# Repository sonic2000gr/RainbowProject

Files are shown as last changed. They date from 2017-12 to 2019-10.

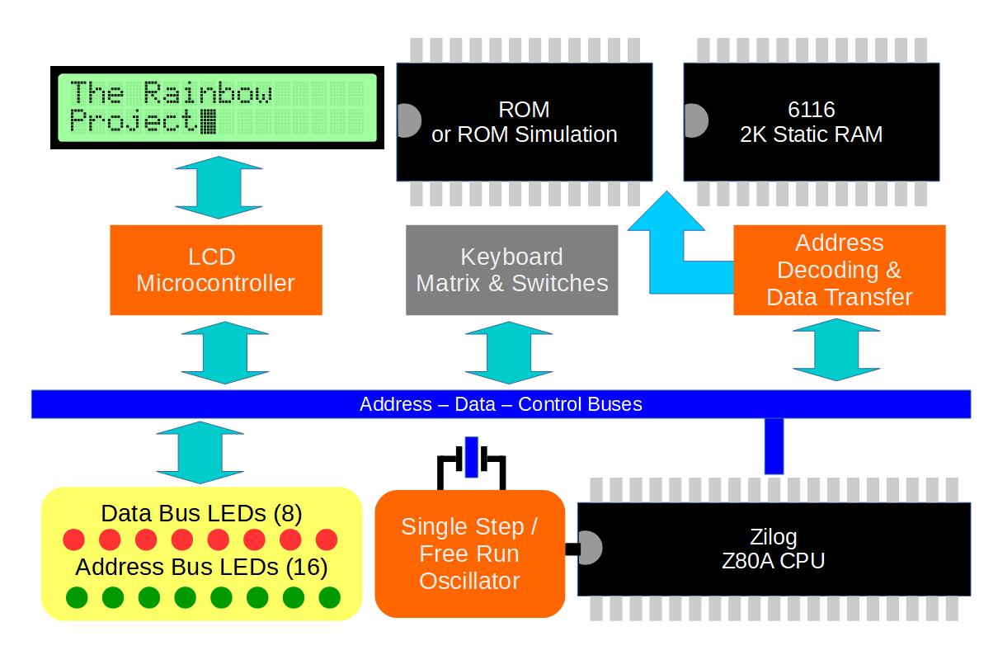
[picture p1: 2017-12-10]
graphics/rainbow diagram.jpg

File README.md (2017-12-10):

<h1>The Rainbow Z80 Project</h1>

<h2>English Version</h2>

This repository contains schematics and info on the Rainbow Project.
This is a long overdue (27 years!) project to create a  Z80 based educational computer. It is inspired by the home micros of the 80s
that used the popular 8bit processor from Zilog.

The Rainbow Project machine planned initial specs are:

<ul>
<li>Z80 CPU with variable clock (0 Hz to maybe 2-4 MHz)</li>
<li>8KB EEPROM hosting monitor / test programs</li>
<li>2KB of static RAM</li>
<li>LCD 20 characters by 4 rows or similar</li>
<li>Status LEDs for all buses (Data, Address, Control)</li>
<li>Possibly HEX keypad for entering opcodes / data</li>
<li>Other features that will come by while experimenting!</li>
</ul>

<h2>Greek Version</h2>

Το παρόν repository περιέχει σχηματικά και πληροφορίες για το Rainbow Project
Το Rainbow Project είναι ένα έργο που έχει αργήσει *μόνο* 27 χρόνια! Άρχισα να το σχεδιάζω το 1990 και πολλά από τα εξαρτήματα του (CPU, RAM)
είχαν αγοραστεί τότε. Τελικά θα πραγματοποιηθεί ως Project του <a href="http://www.schoolspace.gr">SchoolSpace</a> το σχολικό έτος 2017-2018.
Το Rainbow Project είναι εμπνευσμένο από τα πολλά μηχανήματα της δεκαετίας του 80 που βασίζονταν στο δημοφιλή επεξεργαστή Z80 της Zilog.
Χαρακτηριστικά παραδείγματα: 

<ul>
<li>Siclair ZX80 / ZX81 / Spectrum</li>
<li>Amstrad CPC</li>
<li>MSX</li>
</ul>

Οι αρχικές προδιαγραφές του μηχανήματος (θα μεταβληθούν στην πορεία):

<ul>
<li>Επεξεργαστής Z80 με μεταβλητό ρολόι (από 0 Hz ως ίσως 2 ή 4 MHz)</li>
<li>8KB EEPROM με πρόγραμμα monitor και demos / tests</li>
<li>2KB Static RAM</li>
<li>Οθόνη LCD 20X4 η παρόμοια (με οδήγηση από Arduino ή MSP430)</li>
<li>Φωτεινές ενδείξεις με LEDs για όλους τους διαύλους. Το μηχάνημα θα χρησιμοποιείται για εκπαιδευτικούς σκοπούς και θα μπορεί να δείχνει
τα βήματα ανάκλησης / εκτέλεσης εντολών</li>
<li>Πληκτρολόγιο HEX για opcodes / data</li>
<li>Ότι άλλη ιδέα μας έρθει στο μεταξύ!</li>
</ul>

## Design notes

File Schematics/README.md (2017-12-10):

This directory contains schematics in KiCad for the Z80 Rainbow Project

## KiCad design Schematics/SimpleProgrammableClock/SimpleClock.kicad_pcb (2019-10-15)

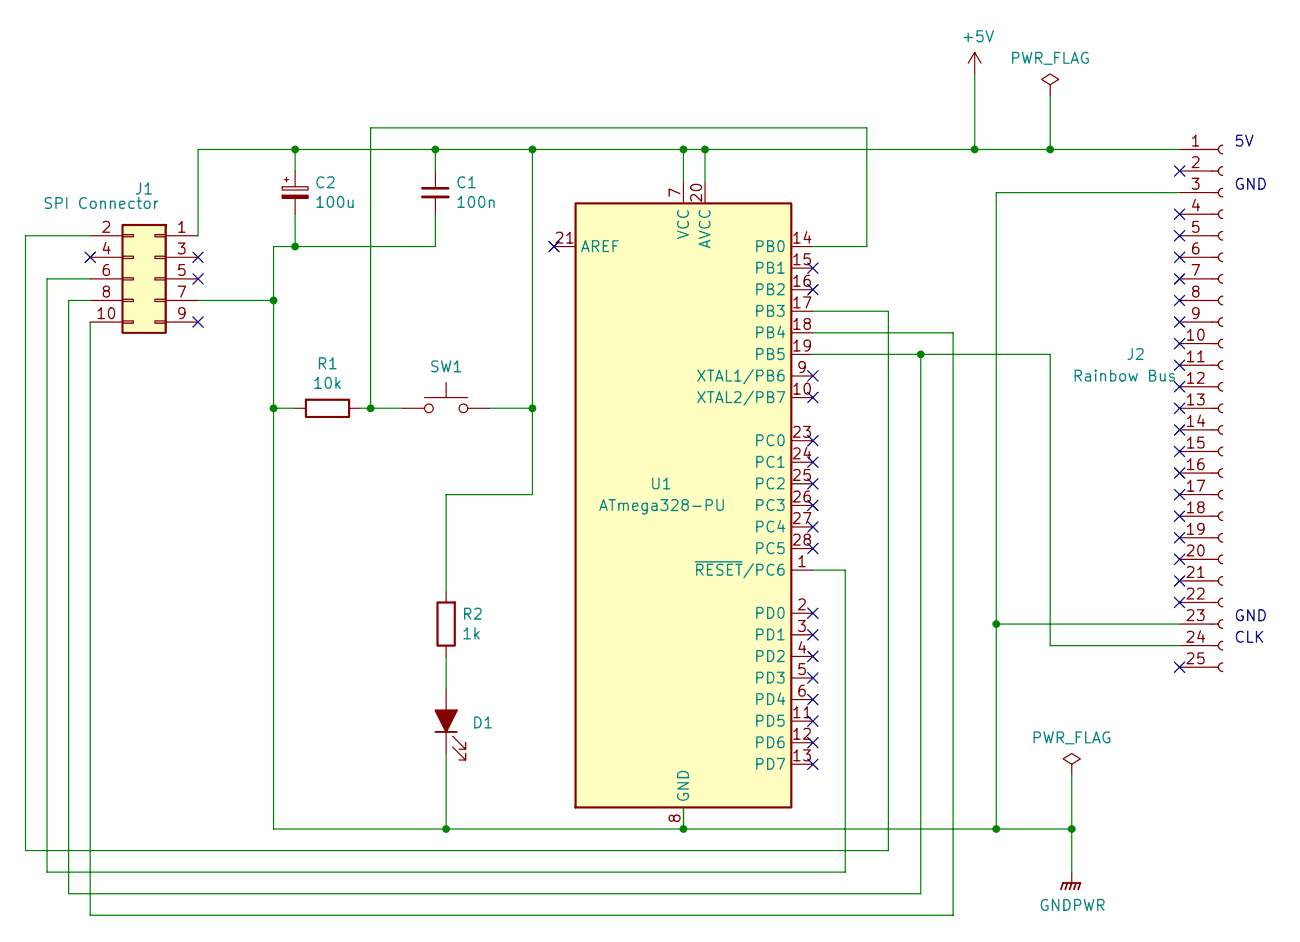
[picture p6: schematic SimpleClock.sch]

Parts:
C1: 100n; C_Disc_D5.1mm_W3.2mm_P5.00mm
C2: 100u; CP_Radial_D8.0mm_P3.50mm
D1: LED_ALT; D_DO-15_P12.70mm_Horizontal
J1: SPI Connector; PinHeader_2x05_P2.54mm_Vertical
J2: Rainbow Bus; PinHeader_1x25_P2.54mm_Vertical
R1: 10k; R_Axial_DIN0207_L6.3mm_D2.5mm_P10.16mm_Horizontal
R2: 1k; R_Axial_DIN0207_L6.3mm_D2.5mm_P10.16mm_Horizontal
SW1: SW; SW_PUSH_6mm_H4.3mm
U1: ATmega328-PU; DIP-28_W7.62mm

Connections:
+5V: C1.1, C2.1, J1.1, J2.1, R2.2, SW1.2, U1.7 (VCC), U1.20 (AVCC)
GNDPWR: C1.2, C2.2, D1.1 (K), J1.7, J2.3, J2.23, R1.2, U1.8 (GND), U1.22 (GND)
unnamed: D1.2 (A), R2.1
unnamed: J1.2, U1.17 (PB3)
unnamed: J1.6, U1.1 (~RESET~/PC6)
unnamed: J1.8, J2.24, U1.19 (PB5)
unnamed: J1.10, U1.18 (PB4)
unnamed: R1.1, SW1.1, U1.14 (PB0)

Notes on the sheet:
CLK
GND

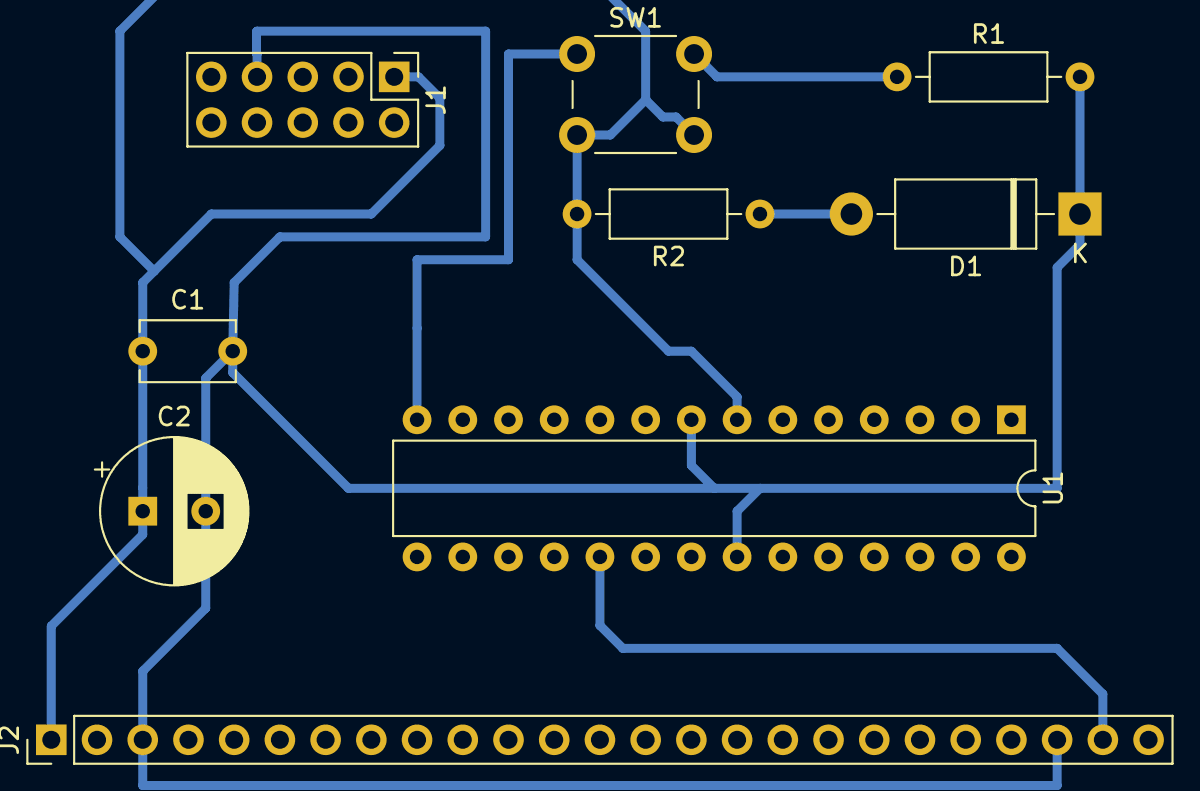
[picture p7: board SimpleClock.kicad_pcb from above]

Board: 2 copper layers, 9 parts (0 on the bottom side), 8 nets.

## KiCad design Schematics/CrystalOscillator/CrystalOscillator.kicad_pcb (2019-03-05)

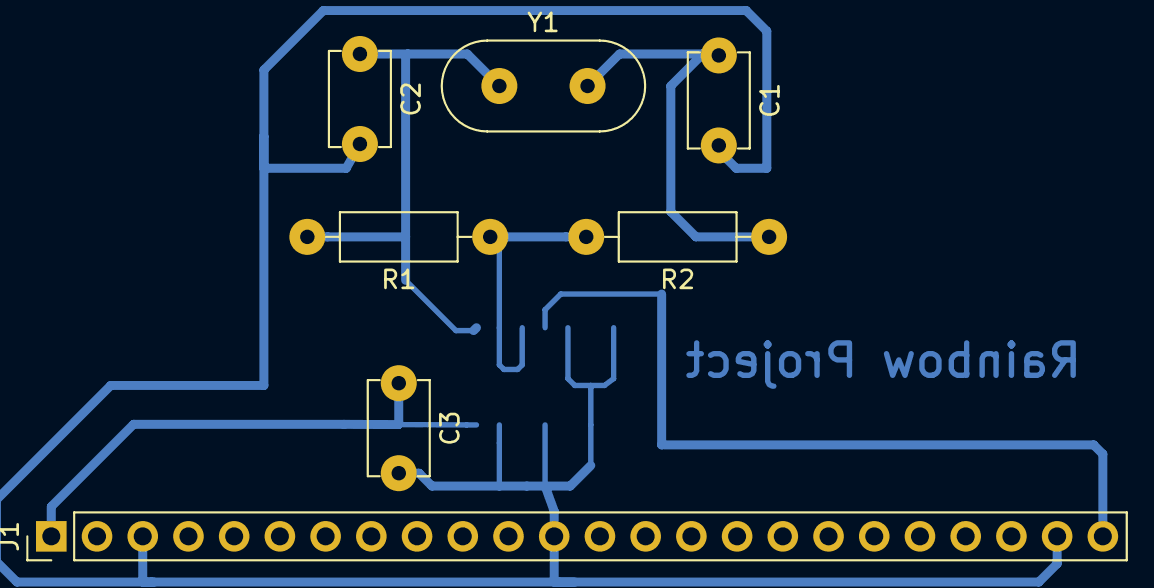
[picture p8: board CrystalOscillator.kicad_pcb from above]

Board: 2 copper layers, 8 parts (1 on the bottom side), 6 nets.

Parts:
C1, C2: 3.3p; C_Disc_D5.1mm_W3.2mm_P5.00mm
C3: 0.1u; C_Disc_D5.1mm_W3.2mm_P5.00mm
J1: Conn_01x24_Female; PinHeader_1x24_P2.54mm_Vertical
R1: 1M; R_Axial_DIN0207_L6.3mm_D2.5mm_P10.16mm_Horizontal
R2: 10k; R_Axial_DIN0207_L6.3mm_D2.5mm_P10.16mm_Horizontal
U1: 74HC14; SOIC-14_3.9x8.7mm_P1.27mm
Y1: 4MHz Crystal; Crystal_HC18-U_Vertical

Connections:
GND: C1.2, C2.2, C3.2, J1.3, J1.12, J1.23, U1.5, U1.7, U1.9, U1.11, U1.13
unnamed: C1.1, R2.1, Y1.2
unnamed: C2.1, R1.2, U1.1, Y1.1
unnamed: J1.24, U1.4
unnamed: R1.1, R2.2, U1.2, U1.3
VCC: C3.1, J1.1, U1.14

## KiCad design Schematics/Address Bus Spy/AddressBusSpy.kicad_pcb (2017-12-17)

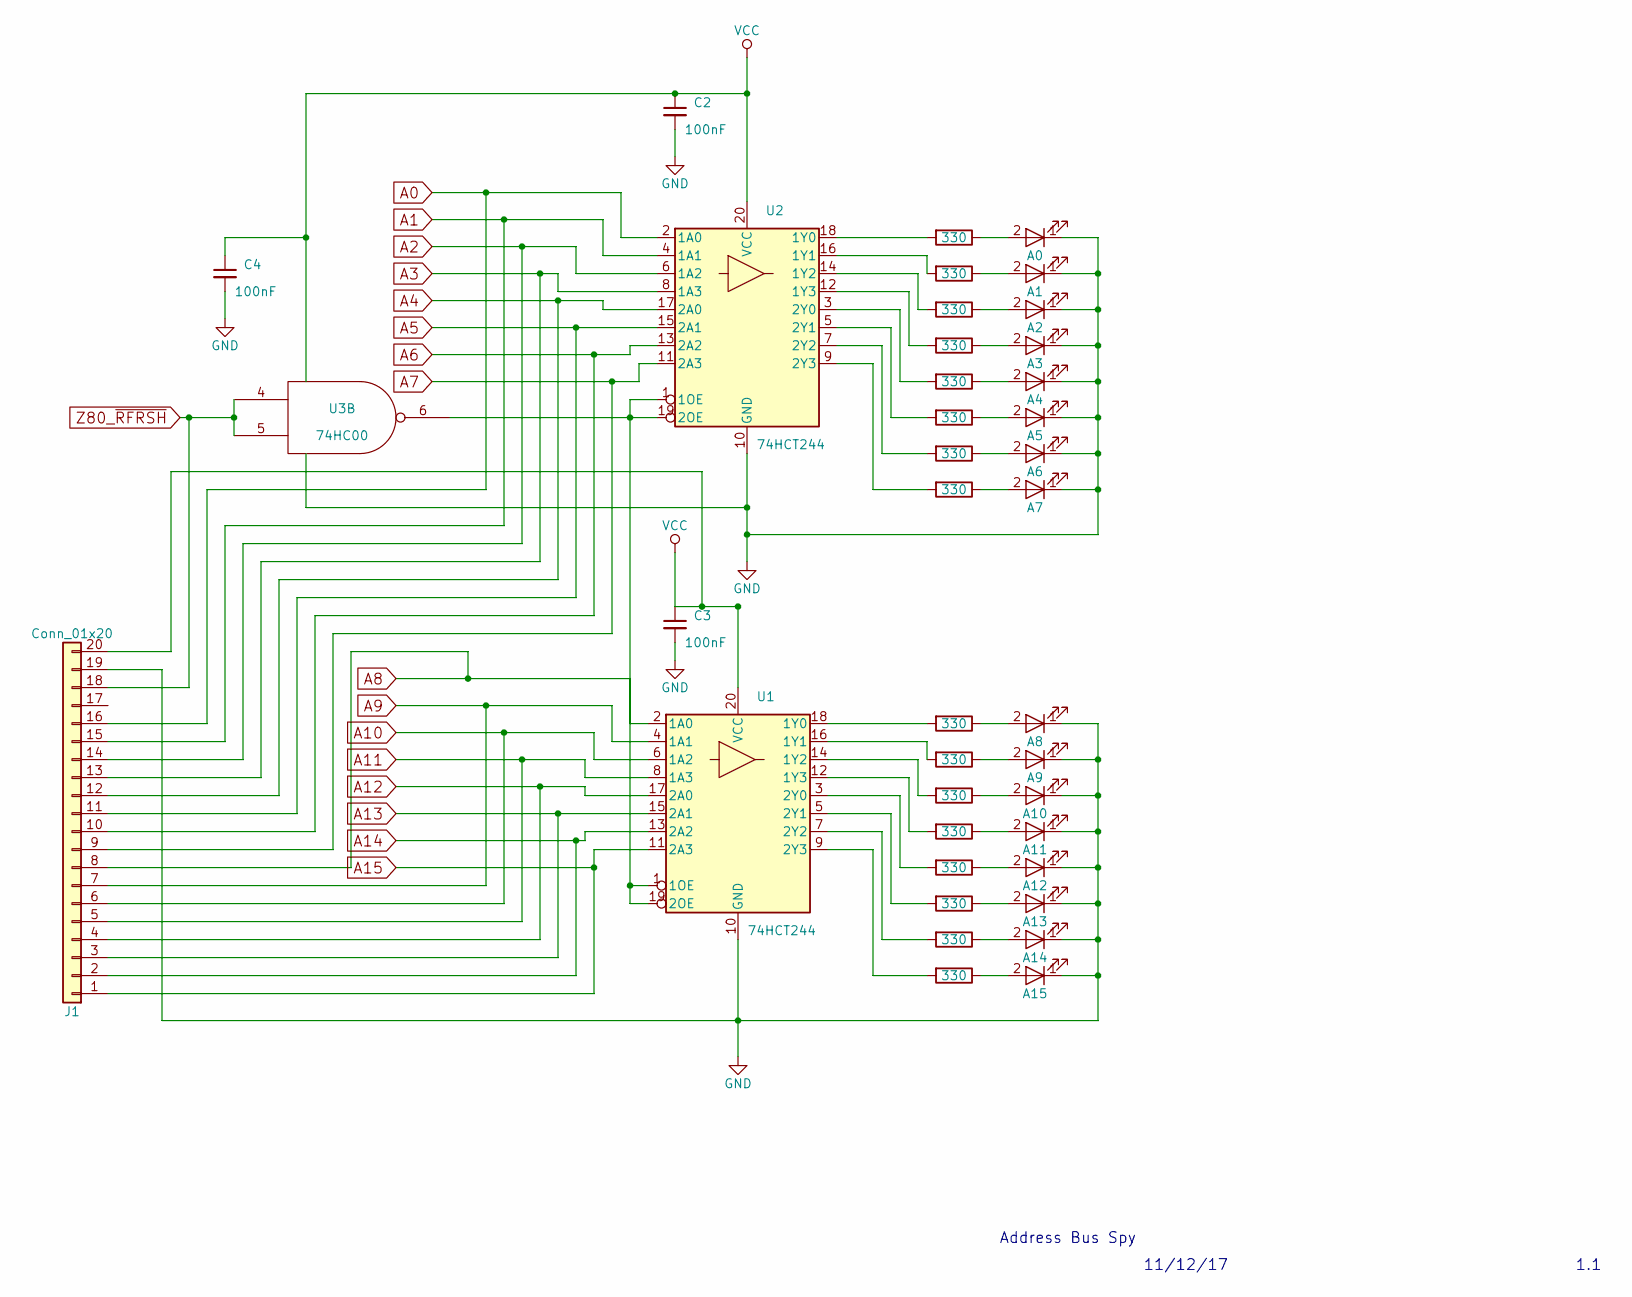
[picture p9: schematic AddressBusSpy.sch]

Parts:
A0, A1, A2, A3, A4, A5, A6, A7, A8, A9, A10, A11, A12, A13, A14, A15: LED; LED_thickpad
C2, C3, C4: 100nF; C_Disc_D10.0mm_W2.5mm_P5.00mm
J1: Conn_01x20; Pin_Header_Straight_1x20_Pitch2.54mm
R1, R2, R3, R4, R5, R6, R7, R8, R9, R10, R11, R12, R13, R14, R15, R16: 330; R_Axial_DIN0204_L3.6mm_D1.6mm_P7.62mm_Horizontal
U1, U2: 74HCT244; DIP-20_thickpad
U3: 74HC00; DIP-14_thickpad

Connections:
A0: J1.16, U2.2 (1A0)
A1: J1.15, U2.4 (1A1)
A2: J1.14, U2.6 (1A2)
A3: J1.13, U2.8 (1A3)
A4: J1.12, U2.17 (2A0)
A5: J1.11, U2.15 (2A1)
A6: J1.10, U2.13 (2A2)
A7: J1.9, U2.11 (2A3)
A8: J1.8, U1.2 (1A0)
A9: J1.7, U1.4 (1A1)
A10: J1.6, U1.6 (1A2)
A11: J1.5, U1.8 (1A3)
A12: J1.4, U1.17 (2A0)
A13: J1.3, U1.15 (2A1)
A14: J1.2, U1.13 (2A2)
A15: J1.1, U1.11 (2A3)
GND: A0.1 (K), A1.1 (K), A2.1 (K), A3.1 (K), A4.1 (K), A5.1 (K), A6.1 (K), A7.1 (K), A8.1 (K), A9.1 (K), A10.1 (K), A11.1 (K), A12.1 (K), A13.1 (K), A14.1 (K), A15.1 (K), C2.2, C3.2, C4.2, J1.19, U1.10 (GND), U2.10 (GND), U3.7 (GND)
unnamed: A0.2 (A), R1.1
unnamed: A1.2 (A), R2.1
unnamed: A2.2 (A), R3.1
unnamed: A3.2 (A), R4.1
unnamed: A4.2 (A), R5.1
unnamed: A5.2 (A), R6.1
unnamed: A6.2 (A), R7.1
unnamed: A7.2 (A), R8.1
unnamed: A8.2 (A), R9.1
unnamed: A9.2 (A), R10.1
unnamed: A10.2 (A), R11.1
unnamed: A11.2 (A), R12.1
unnamed: A12.2 (A), R13.1
unnamed: A13.2 (A), R14.1
unnamed: A14.2 (A), R15.1
unnamed: A15.2 (A), R16.1
unnamed: R1.2, U2.18 (1Y0)
unnamed: R2.2, U2.16 (1Y1)
unnamed: R3.2, U2.14 (1Y2)
unnamed: R4.2, U2.12 (1Y3)
unnamed: R5.2, U2.3 (2Y0)
unnamed: R6.2, U2.5 (2Y1)
unnamed: R7.2, U2.7 (2Y2)
unnamed: R8.2, U2.9 (2Y3)
unnamed: R9.2, U1.18 (1Y0)
unnamed: R10.2, U1.16 (1Y1)
unnamed: R11.2, U1.14 (1Y2)
unnamed: R12.2, U1.12 (1Y3)
unnamed: R13.2, U1.3 (2Y0)
unnamed: R14.2, U1.5 (2Y1)
unnamed: R15.2, U1.7 (2Y2)
unnamed: R16.2, U1.9 (2Y3)
unnamed: U1.1 (1OE), U1.19 (2OE), U2.1 (1OE), U2.19 (2OE), U3.6
VCC: C2.1, C3.1, C4.1, J1.20, U1.20 (VCC), U2.20 (VCC), U3.14 (VCC)
Z80_~RFRSH: J1.18, U3.4, U3.5

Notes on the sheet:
Address Bus Spy
11/12/17
1.1

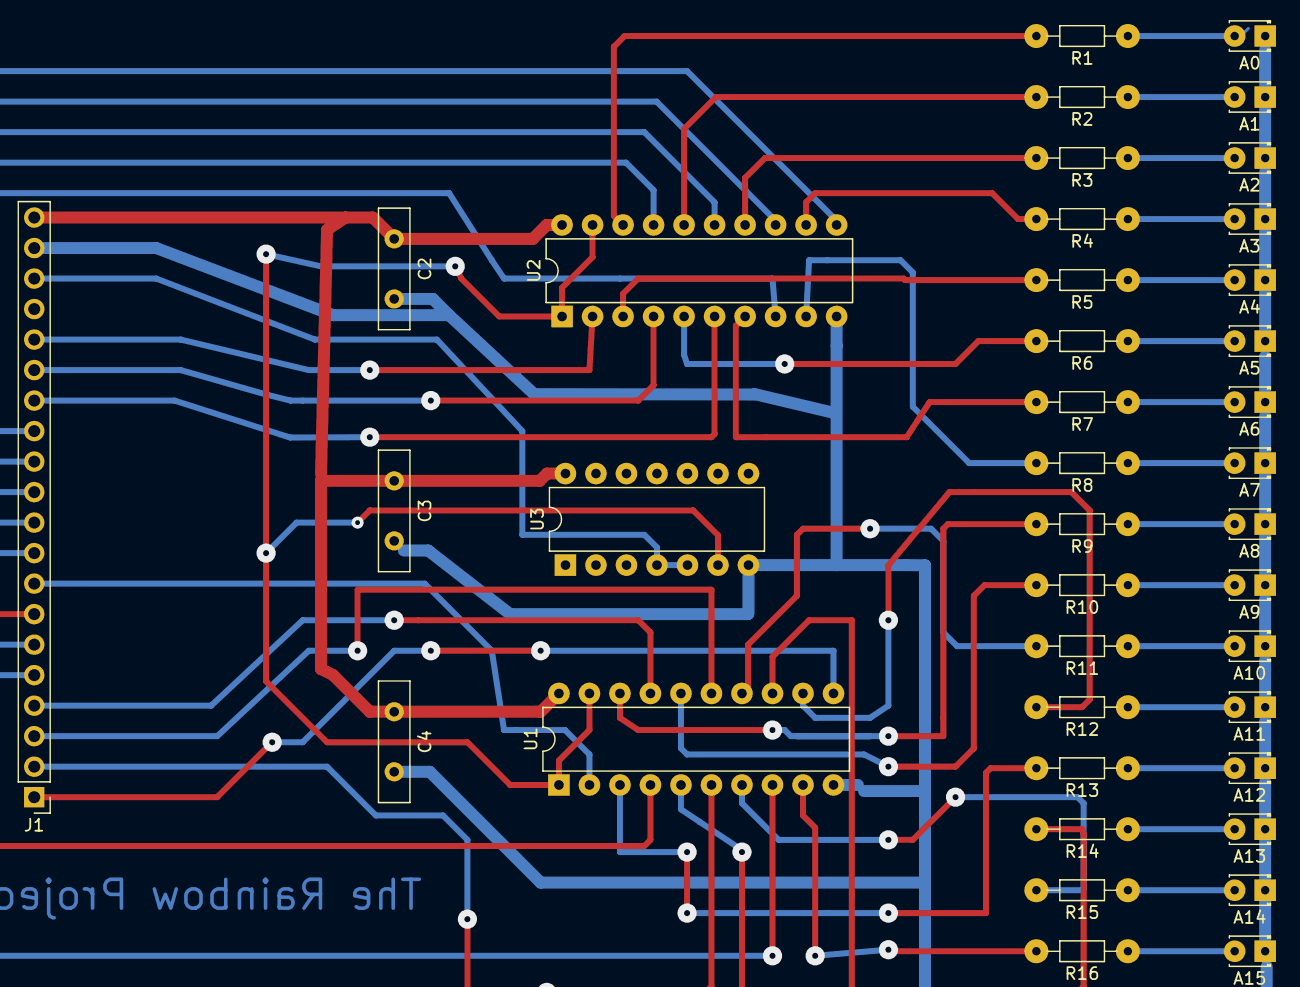
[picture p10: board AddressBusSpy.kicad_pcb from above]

Board: 2 copper layers, 39 parts (0 on the bottom side), 52 nets.

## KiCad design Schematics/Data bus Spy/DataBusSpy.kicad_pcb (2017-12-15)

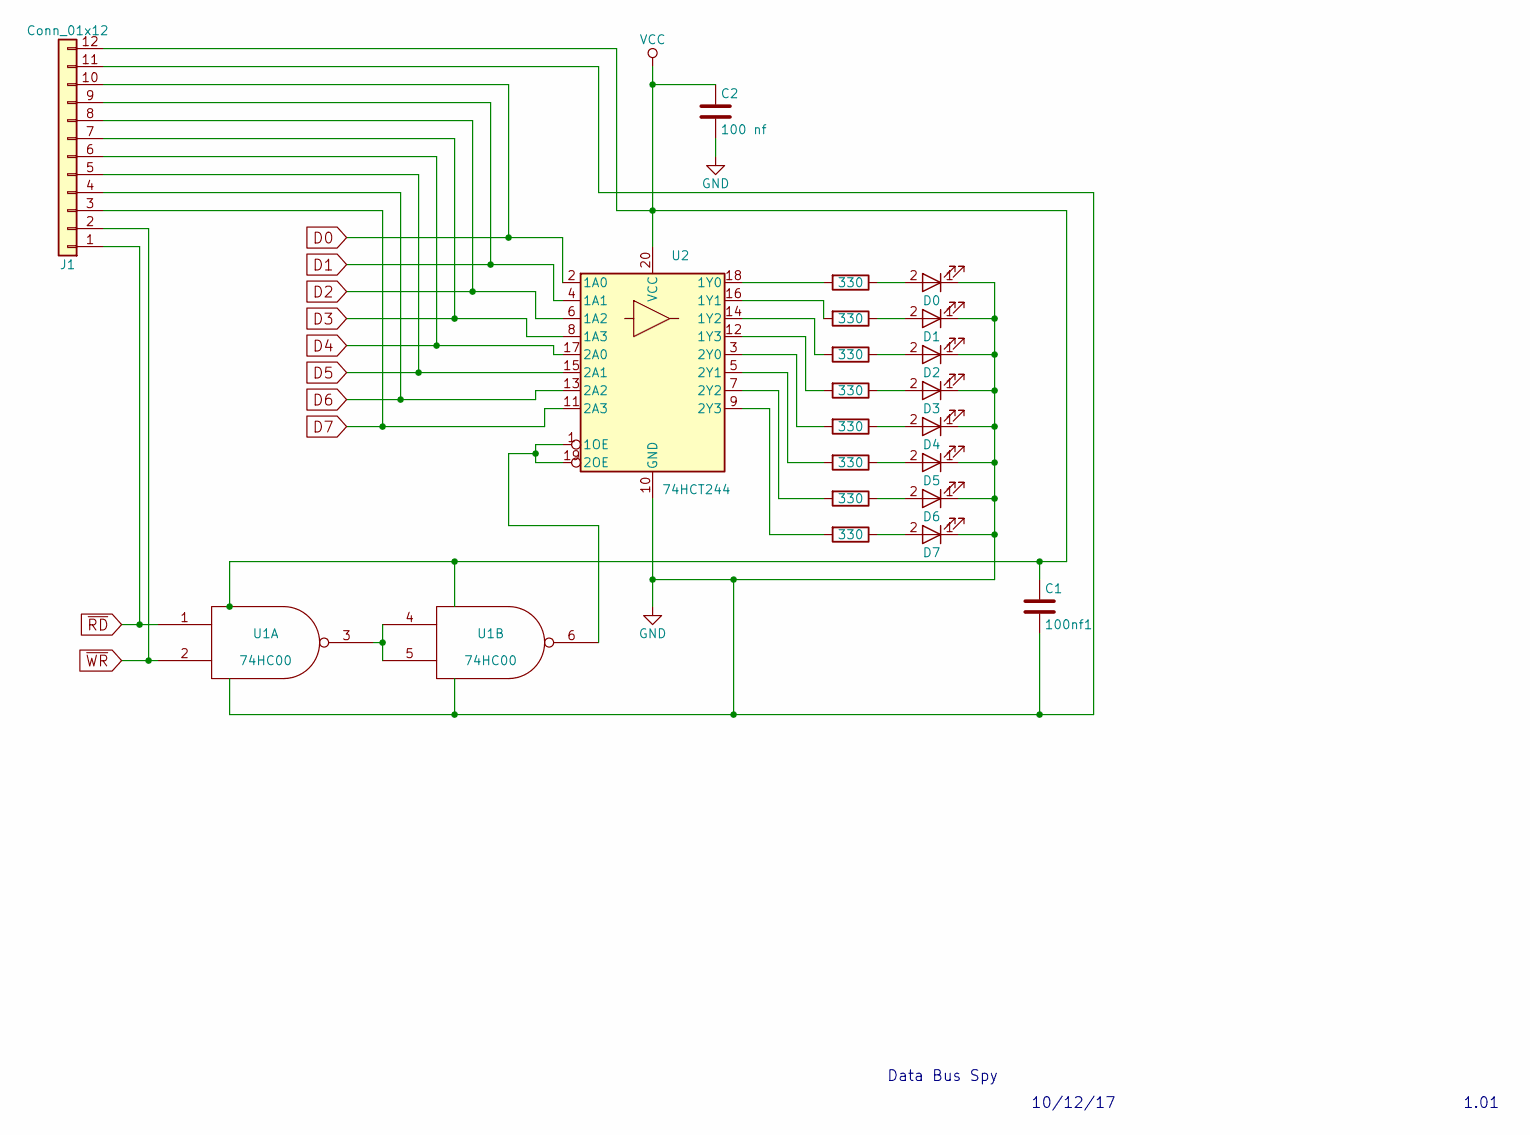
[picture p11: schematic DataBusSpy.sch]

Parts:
100nf1: C1; C_Disc_D10.0mm_W2.5mm_P5.00mm
C2: 100 nf; C_Disc_D10.0mm_W2.5mm_P5.00mm
D0, D1, D2, D3, D4, D5, D6, D7: LED; LED_thickpad
J1: Conn_01x12; Pin_Header_Straight_1x12_thickpad
R1, R2, R3, R4, R5, R6, R7, R8: 330; Resistor_thickpad
U1: 74HC00; DIP-14_thickpad
U2: 74HCT244; DIP-20_thickpad

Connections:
D0: J1.10, U2.2 (1A0)
D1: J1.9, U2.4 (1A1)
D2: J1.8, U2.6 (1A2)
D3: J1.7, U2.8 (1A3)
D4: J1.6, U2.17 (2A0)
D5: J1.5, U2.15 (2A1)
D6: J1.4, U2.13 (2A2)
D7: J1.3, U2.11 (2A3)
GND: 100nf1.1, C2.2, D0.1 (K), D1.1 (K), D2.1 (K), D3.1 (K), D4.1 (K), D5.1 (K), D6.1 (K), D7.1 (K), J1.11, U1.7 (GND), U2.10 (GND)
unnamed: D0.2 (A), R1.1
unnamed: D1.2 (A), R2.1
unnamed: D2.2 (A), R3.1
unnamed: D3.2 (A), R4.1
unnamed: D4.2 (A), R5.1
unnamed: D5.2 (A), R6.1
unnamed: D6.2 (A), R7.1
unnamed: D7.2 (A), R8.1
unnamed: R1.2, U2.18 (1Y0)
unnamed: R2.2, U2.16 (1Y1)
unnamed: R3.2, U2.14 (1Y2)
unnamed: R4.2, U2.12 (1Y3)
unnamed: R5.2, U2.3 (2Y0)
unnamed: R6.2, U2.5 (2Y1)
unnamed: R7.2, U2.7 (2Y2)
unnamed: R8.2, U2.9 (2Y3)
unnamed: U1.3, U1.4, U1.5
unnamed: U1.6, U2.1 (1OE), U2.19 (2OE)
VCC: 100nf1.2, C2.1, J1.12, U1.14 (VCC), U2.20 (VCC)
~RD: J1.1, U1.1
~WR: J1.2, U1.2

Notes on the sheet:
Data Bus Spy
10/12/17
1.01

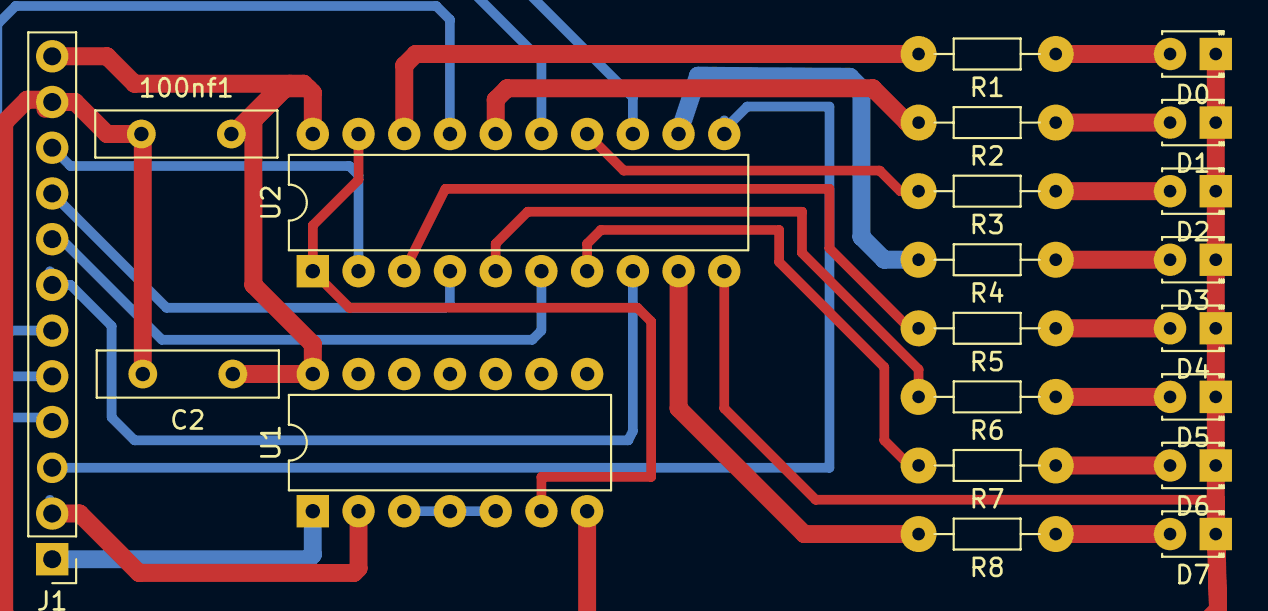
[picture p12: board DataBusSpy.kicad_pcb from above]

Board: 2 copper layers, 21 parts (0 on the bottom side), 30 nets.

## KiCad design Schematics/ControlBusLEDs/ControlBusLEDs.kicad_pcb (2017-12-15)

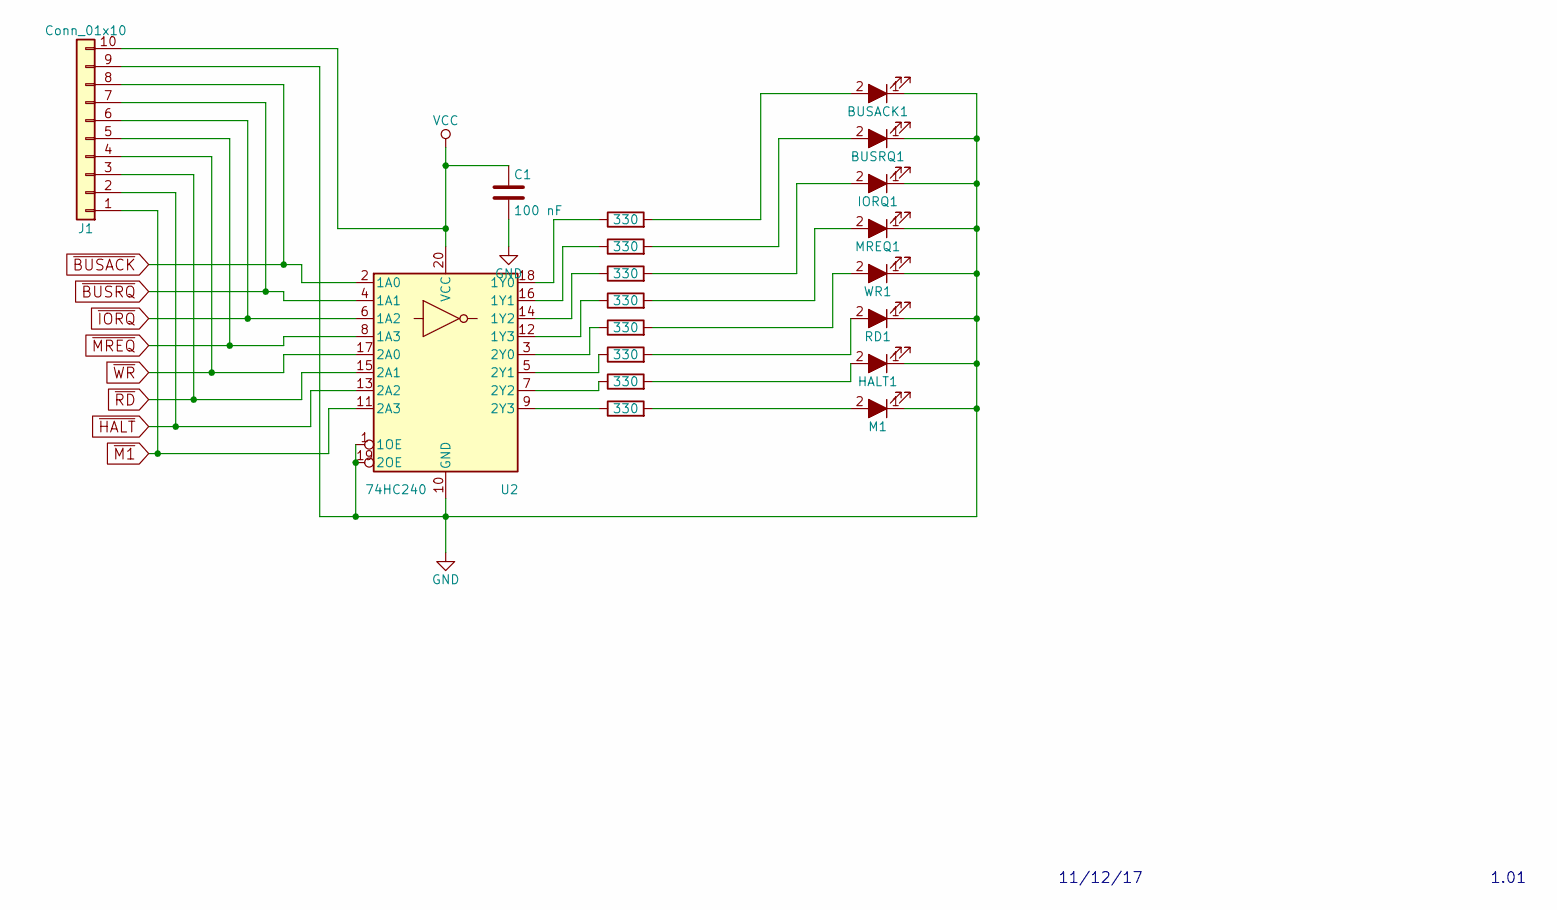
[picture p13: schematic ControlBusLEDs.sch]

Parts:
BUSACK1: LED_ALT; LED_D1.8mm_W3.3mm_H2.4mm
BUSRQ1: LED_ALT; LED_D1.8mm_W3.3mm_H2.4mm
C1: 100 nF; C_Disc_D10.0mm_W2.5mm_P5.00mm
HALT1: LED_ALT; LED_D1.8mm_W3.3mm_H2.4mm
IORQ1: LED_ALT; LED_D1.8mm_W3.3mm_H2.4mm
J1: Conn_01x10; Pin_Header_Straight_1x10_Pitch2.54mm
M1: LED_ALT; LED_D1.8mm_W3.3mm_H2.4mm
MREQ1: LED_ALT; LED_D1.8mm_W3.3mm_H2.4mm
R1, R2, R3, R4, R5, R6, R7, R8: 330; R_Axial_DIN0204_L3.6mm_D1.6mm_P7.62mm_Horizontal
RD1: LED_ALT; LED_D1.8mm_W3.3mm_H2.4mm
U2: 74HC240; DIP-20_W7.62mm
WR1: LED_ALT; LED_D1.8mm_W3.3mm_H2.4mm

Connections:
GND: BUSACK1.1 (K), BUSRQ1.1 (K), C1.2, HALT1.1 (K), IORQ1.1 (K), J1.9, M1.1 (K), MREQ1.1 (K), RD1.1 (K), U2.1 (1OE), U2.10 (GND), U2.19 (2OE), WR1.1 (K)
unnamed: BUSACK1.2 (A), R1.2
unnamed: BUSRQ1.2 (A), R2.2
unnamed: HALT1.2 (A), R7.2
unnamed: IORQ1.2 (A), R3.2
unnamed: M1.2 (A), R8.2
unnamed: MREQ1.2 (A), R4.2
unnamed: R1.1, U2.18 (1Y0)
unnamed: R2.1, U2.16 (1Y1)
unnamed: R3.1, U2.14 (1Y2)
unnamed: R4.1, U2.12 (1Y3)
unnamed: R5.1, U2.3 (2Y0)
unnamed: R5.2, WR1.2 (A)
unnamed: R6.1, U2.5 (2Y1)
unnamed: R6.2, RD1.2 (A)
unnamed: R7.1, U2.7 (2Y2)
unnamed: R8.1, U2.9 (2Y3)
VCC: C1.1, J1.10, U2.20 (VCC)
~BUSACK: J1.8, U2.2 (1A0)
~BUSRQ: J1.7, U2.4 (1A1)
~HALT: J1.2, U2.13 (2A2)
~IORQ: J1.6, U2.6 (1A2)
~M1: J1.1, U2.11 (2A3)
~MREQ: J1.5, U2.8 (1A3)
~RD: J1.3, U2.15 (2A1)
~WR: J1.4, U2.17 (2A0)

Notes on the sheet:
11/12/17
1.01

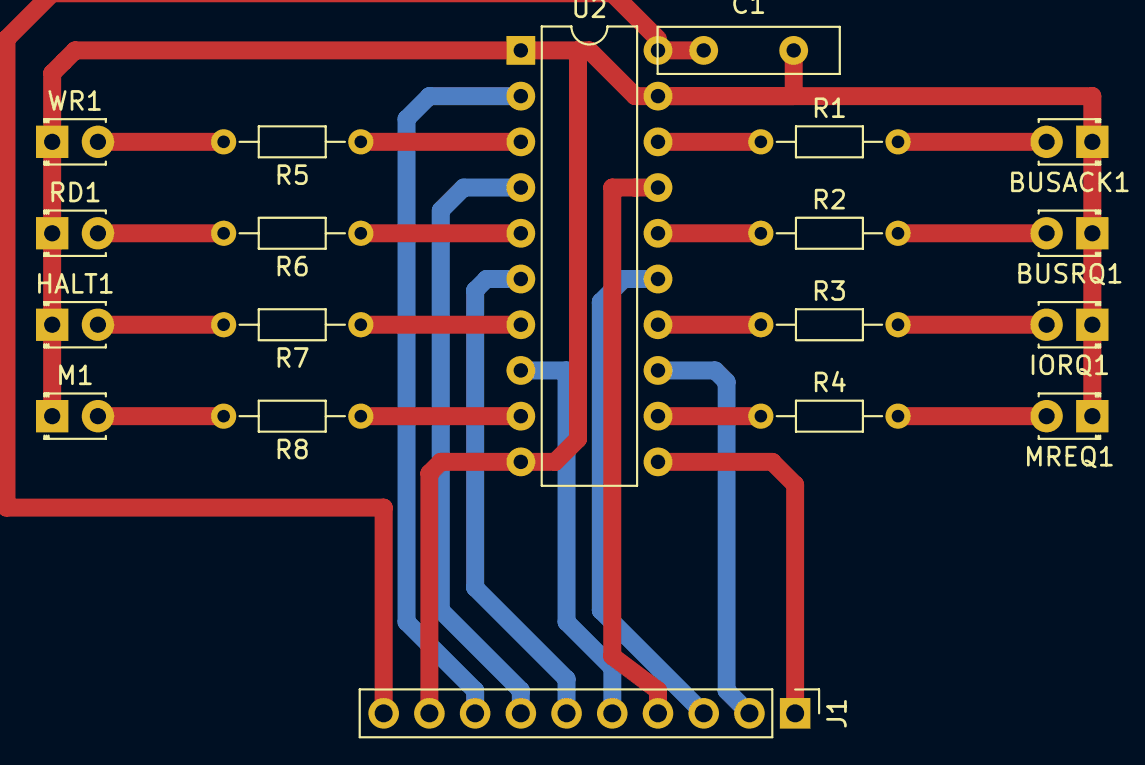
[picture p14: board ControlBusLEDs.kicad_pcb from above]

Board: 2 copper layers, 19 parts (0 on the bottom side), 26 nets.

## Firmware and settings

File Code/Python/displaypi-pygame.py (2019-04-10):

# -*- coding: utf-8 -*-
#
# pygame displaypi
#

import pygame
import RPi.GPIO as GPIO
from pygame.locals import *
from enum import Enum
from sys import exit
from copy import copy

class Color(Enum):
    Black = (0x00, 0x00, 0x00)
    Green = (0x21, 0xC8, 0x42)
    LightGreen = (0x5E, 0xDC, 0x78)
    Blue = (0x54, 0x55, 0xED)
    LightBlue = (0x7D, 0x76, 0xFC)
    DarkRed = (0xD4, 0x52, 0x4D)
    Cyan = (0x42, 0xEB, 0xF5)
    Red = (0xFC, 0x55, 0x54)
    LightRed = (0xFF, 0x79, 0x78)
    DarkYellow = (0xD4, 0xC1, 0x54)
    LightYellow = (0xE6, 0xCE, 0x80)
    DarkGreen = (0x21, 0xB0, 0x3B)
    Magenta = (0xC9, 0x5B, 0xBA)
    Gray = (0xCC, 0xCC, 0xCC)
    White = (0xFF, 0xFF, 0xFF)

class Logo(object):
    def __init__(self, logosize):
        if logosize == 32:
            self.logo = pygame.transform.scale(pygame.image.load("logo2.png"), (100,100))
        else:
            self.logo = pygame.transform.scale(pygame.image.load("logo2.png"), (75,75))
        self.visibility = False
    def setVisible(self, visibility):
        if visibility:
            self.visibility = True
        else:
            self.visibility = False
    def setPos(self, pos):
        self.pos = pos
    def getPos(self):
        return self.pos
    def render(self, screen):
        if self.visibility:
            screen.blit(self.logo, self.pos.translatePos())
    

class Cursor(object):
    def __init__(self, cursorcolor, cursorsize):
        self.cursorcolor = cursorcolor
        self.cursorsize = cursorsize
        self.visibility = False
    def setPos(self, pos):
        self.pos = pos
    def getPos(self):
        return self.pos
    def setVisible(self, visibility):
        if visibility:
            self.visibility = True
        else:
            self.visibility = False
    def render(self, screen):
        if self.visibility:
            pygame.draw.rect(screen, self.cursorcolor.value, (self.pos.translatePosX(), self.pos.translatePosY(),
                                                              self.cursorsize, self.cursorsize))
                
class Position(object):
    def __init__(self, wposx, wposy, fontsize):
        self.wposx = wposx
        self.wposy = wposy
        self.fontsize = fontsize
        self.x = 0
        self.y = 0
    def setPos(self, x, y):
        self.x = x
        self.y = y
    def getPos(self):
        return (self.x, self.y)
    def translatePos(self):
        return (self.wposx + self.fontsize * self.x, self.wposy + self.fontsize * self.y)
    def translatePosX(self):
        return self.wposx + self.fontsize * self.x
    def translatePosY(self):
        return self.wposy + self.fontsize * self.y
    def nextChar(self):
        self.x += 1
        if self.x == 32:
            self.x = 0
            self.y += 1
            if self.y == 25:
                self.y = 0
    def nextLine(self):
        self.y += 1
        self.x = 0
        if self.y == 25:
            self.y = 0
        

class Text(object):
    def __init__(self, textfont, textsize):
        self.tlist = list()
        self.textfont = textfont
        self.textsize = textsize
    def add(self, letter, pos, textcolor = Color.Black, surfacecolor = Color.Cyan):
        thepos = copy(pos)
        self.tlist.append((letter, thepos, textcolor, surfacecolor))
    def clear(self):
        del self.tlist[:]
        textpos.setPos(0,0)
        cursorpos.setPos(0,0)
    def render(self, screen):
        for item in self.tlist:
            thetext = self.textfont.render(item[0], True, item[2].value, item[3].value)
            screen.blit(thetext, item[1].translatePos())

            
class Screen(object):
    def __init__(self):
        self.width = pygame.display.Info().current_w
        self.height = pygame.display.Info().current_h
        #self.width = 1024
        #self.height = 768
        if self.height < 800:
            self.wheight = 600
            self.wwidth = 800
        else:
            self.wheight = 800
            self.wwidth = 1024
    def getFontSize(self):
        if self.wheight == 800:
            return 32
        return 24


class Border(object):
    def __init__(self, thescreen):
        self.bwidth = thescreen.width - thescreen.wwidth
        self.bheight = thescreen.height - thescreen.wheight
    def getWindowPos(self):
        return (self.bwidth / 2, self.bheight / 2)
    
#
# Process the event queue 
# returns true if user clicks close
# or any key is pressed
#

def getQuit():
    for event in pygame.event.get():
      if event.type == QUIT:
        return True
      if event.type == KEYDOWN:
        if event.key == K_q:
            return True

# Callback routine for Z80 Write

def z80_write():
  global inchannel, queue, textpos, thetext, textcolor,\
         surfacecolor, cursorpos, logopos, logo, waiting, showti

  mul = 1
  data = 0
  for i in inchannel:
      data += GPIO.input(i) * mul
      mul = mul * 2

  #print "Data ", data

  if data == 255:
      # All reset
      textpos.setPos(0,0)
      logo.setVisible(False)
      thetext.clear()
      waiting = 0
      return

  # Make logo visible
  
  if waiting == 0 and data == 128:
      logo.setVisible(True)
      return

  # Make logo invisible
  
  if waiting == 0 and data == 129:
      logo.setVisible(False)
      return

  # Clear screen - this does not affect logo

  if waiting == 0 and data == 254:
      # Clear screen
      textpos.setPos(0,0)
      thetext.clear()
      return

  if waiting == 0 and data == 253:
      # Set position command, wait for two more bytes
      waiting = 2
      queue.append(data)
      return

  if waiting == 0 and data == 252:
      # Set logo position wait for two more bytes
      waiting = 2
      queue.append(data)
      return

  if waiting == 0 and data == 251:
      # Show TI Screen
      showti = True
      return
    
  if waiting:
      queue.append(data)
      waiting = waiting - 1
      if waiting == 0:
          # process queue
          if queue[0] == 253:
              textpos.setPos(queue[1], queue[2])
          if queue[0] == 252:
              logopos.setPos(queue[1], queue[2])
          del queue[:]
          return
      return

  if data !=0 :
      textpos.nextChar()
      thetext.add(chr(data), textpos, textcolor, surfacecolor)
  return

def TI_Screen():
    textpos.setPos(0,0)
    thetext.clear()
    logopos.setPos(13,6)
    logo.setPos(logopos)
    logo.setVisible(True)
        
    textpos.setPos(1, 3)
    for i in Color:
        thetext.add('A', textpos, i, i)
        textpos.nextChar()
        thetext.add('A', textpos, i, i)
        textpos.nextChar()
    textpos.nextLine()
    textpos.nextChar()
    for i in Color:
        thetext.add('A', textpos, i, i)
        textpos.nextChar()
        thetext.add('A', textpos, i, i)
        textpos.nextChar()
    
    textpos.setPos(6,10)
    thetext.add("THE RAINBOW PROJECT", textpos)
    textpos.setPos(3,12)
    thetext.add("Z80 EXPERIMENTAL COMPUTER", textpos)
    textpos.setPos(3,18)
    thetext.add("READY - WAITING FOR Z80 CPU", textpos)
    textpos.setPos(1,20)
    for i in Color:
        thetext.add('A', textpos, i, i)
        textpos.nextChar()
        thetext.add('A', textpos, i, i)
        textpos.nextChar()
    textpos.nextLine()
    textpos.nextChar()
    for i in Color:
        thetext.add('A', textpos, i, i)
        textpos.nextChar()
        thetext.add('A', textpos, i, i)
        textpos.nextChar()
    textpos.setPos(2,23)
    thetext.add(chr(169)+" 2017 - 2019 SCHOOLSPACE.GR", textpos)
    return

# Initialize RPi.GPIO

GPIO.setmode(GPIO.BCM)

# GPIO10 = Z80 Write (active low)

GPIO.setup(10, GPIO.IN)
GPIO.add_event_detect(10, GPIO.FALLING)

# Data bus D7-D0 = 14,15,18,23,24,25,8,7

inchannel = [7,8,25,24,23,18,15,14]
GPIO.setup(inchannel, GPIO.IN)
  
# Initialize command/data queue

queue = list()
waiting = 0

# Initialize the pygame library

pygame.init()

# Initialize the screen object
    
thescreen = Screen()

# Get window width / height (two possible sets only)
    
wwidth, wheight = thescreen.wwidth, thescreen.wheight

# Get whole screen width / height
    
width, height = thescreen.width, thescreen.height

# Get border object, this also calculates window position
    
theborder = Border(thescreen)

# Get fontsize / cursorsize

fontsize = cursorsize = logosize = thescreen.getFontSize()

# Set some sane colors
    
surfacecolor = Color.Cyan   
bordercolor = Color.Red
textcolor = Color.Black
cursorcolor = Color.Blue

# Set screen
    
screen = pygame.display.set_mode((width, height),  DOUBLEBUF|FULLSCREEN , 32)

# Calculate window position
    
wposx, wposy = theborder.getWindowPos()

# Get a text position object and a cursor position object

textpos = Position(wposx, wposy, fontsize)
cursorpos = Position(wposx, wposy, fontsize)
logopos = Position(wposx, wposy, fontsize)
    
# Start screen setup
    
pygame.display.set_caption("Display Pi")

# Mouse should not be visible during displaypi operation
    
pygame.mouse.set_visible(False)

# Set font and size according to screen size
    
textfont = pygame.font.Font("PressStart2P.ttf",fontsize)
thetext = Text(textfont, fontsize)
textpos.setPos(0,0)
logopos.setPos(0,0)
cursorpos.setPos(0,0)
logo = Logo(logosize)
showti = True

def main():
    # Load rainbow logo and set to visible
    global showti    
    thecursor = Cursor(cursorcolor, cursorsize)
    thecursor.setPos(cursorpos)
    thecursor.setVisible(False)
    #thetext.clear()
    #textpos.setPos(5,1)
    #textpos.setPos(5,3)
    #thetext.add("Z80 COMPUTER SYSTEM", textpos)
    #textpos.setPos(2,5)
    #thetext.add("PRESS",textpos)
    #textpos.setPos(2,7)
    #thetext.add("1 FOR SYSTEM DEMO", textpos)
    #textpos.setPos(2,9)
    #thetext.add("2 FOR TRIVIA GAME", textpos)
    
    # Begin main loop
    thetext.clear()
    textpos.setPos(0,0)
    logo.setVisible(False)
    endprogram = False
    #clock = pygame.time.Clock()
    while not endprogram:      

        if GPIO.event_detected(10):
            z80_write()
          
        # fill screen with border color
        screen.fill(bordercolor.value)

        # draw our window
        pygame.draw.rect(screen, surfacecolor.value ,(wposx, wposy, wwidth, wheight))

        # Render the content
        if showti:
            TI_Screen()
            showti = False
        
        thetext.render(screen)
        thecursor.render(screen)
        logo.render(screen)
        #time = clock.tick()
        #fps = textfont.render(str(1000/time), True, Color.Black.value, Color.Green.value)
        #screen.blit(fps, (0,0))
        endprogram = getQuit()
        pygame.display.update()

    # shutdown pygame and exit program
    pygame.quit()
    exit()

# Start program
if __name__ == "__main__":
    main()

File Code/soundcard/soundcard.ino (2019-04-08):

/* Rainbow Project Sound card
 *  Based on Atmega 328p
 */

/* The following pins / outputs are used
 *  
 *  Arduino Digital Pin 8 (328p Pin 14, PortB0) => Output to AMP
 *  
 *  Atmega 328P Pins    Function
 *  ============================
 *  PORTD7 13           Z80 D7
 *  PORTD6 12           Z80 D6
 *  PORTD5 11           Z80 D5
 *  PORTD4 6            Z80 D4
 *  PORTD3 5            Z80 D3
 *  PORTD2 4            Z80 D2
 *  PORTD1 3            Z80 D1
 *  PORTD0 2            Z80 D0
 *  
 *  PORTC0 23           SEL2
 *  PORTC1 24           Z80 WR
 */

void setup() {
  // Set entire Port B as inputs, except PB0
  
  DDRB = 0b00000001;
  
  // Set pull up resistors for entire port B except bit 0
  
  PORTB = 0b11111110;
  
  // Set entire Port C as inputs
  
  DDRC = 0b00000000;

  // Set pull up resistors for entire port C except bit 0/1

  PORTC = 0b11111100;
  
  // Set entire Port D as inputs

  DDRD = 0b00000000;
}

void loop() {
  while (true) {
  }
}

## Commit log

2017-12-10 Add initial schematics for Z80/ROM test circuits
    [74HC138Test.sch, ControlBusLEDs.sch, Z80Rom.sch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]
2017-12-10 Minor fixes in 74HC138 test schematic
    [74HC138Test.sch]
2017-12-10 Minor nits in control bus LEDs schematic
    [ControlBusLEDs.sch]
2017-12-10 Add Data Bus Spy schematic
    [DataBusSpy.sch]
2017-12-11 Slight changes in DataBus Spy
    [DataBusSpy.sch]
2017-12-11 Remove connector from ControlBusLEDs schematic. Add .gitignore
    [ControlBusLEDs.sch]
2017-12-11 Add initial version of Address Decoder
    [AddressDecoder.sch]
2017-12-11 Add initial version of Address Bus Spy
    [AddressBusSpy.sch]
2017-12-14 Update ControlBusLEDs schematic and add initial PCB
    [ControlBusLEDs.kicad_pcb, ControlBusLEDs.sch]
2017-12-15 Add Data Bus Spy PCB and custom footprint library
    [DataBusSpy.kicad_pcb, DataBusSpy.sch]
2017-12-15 Add RAM test circuit (breadboard)
    [RamTest.sch]
2017-12-17 Add PCB for Address Bus Spy schematic
    [AddressBusSpy.kicad_pcb, AddressBusSpy.sch]
2018-01-13 Add prelim version of display driver (MSP430G2553 code)
2018-01-15 Add initial version of IDI schematic
    [idi.kicad_pcb, idi.sch]
2018-01-23 Add preliminary Z80 mainboard schematics
    [Z80Mainboard.sch]
2018-03-09 Add a buffer stage for the IORQ signal in IDI - required for reliable operation
    [idi.sch]
2018-03-15 Add revision 1.1 of Z80 Mainboard
    [Z80Mainboard.sch]
2018-03-20 Add initial version of programmable clock
    [ProgrammableClock.kicad_pcb, ProgrammableClock.sch]
2018-04-22 Add Z80 assembly source / binary for the Rainbow Project Demo
2019-01-18 Update schematics to KiCad 5
    [74HC138Test.sch, AddressBusSpy.sch, AddressDecoder.sch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]
2019-01-18 Add initial code and schematic for keyboard interface
    [IODecoder-2018-12-28-10-11-45.sch, IODecoder-2018-12-29-13-07-01.sch, IODecoder.sch]
2019-01-18 Minor changes in IO Decoder schematic
    [IODecoder.sch]
2019-01-21 Move IO Decoder to schematics and add Speaker and Joystick Ports
    [IODecoder-2018-12-28-10-11-45.sch, IODecoder-2018-12-29-13-07-01.sch, IODecoder.sch]
2019-01-21 Add soundcard initial schematic
    [soundcard.kicad_pcb, soundcard.sch]
2019-01-23 Save all Schematics again to overcome problems with version change
    [74HC138Test.sch, AddressBusSpy.sch, AddressDecoder.sch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]
2019-03-04 Add schematic and PCB for 4MHz Crystal Oscillator
    [CrystalOscillator.kicad_pcb, CrystalOscillator.sch]
2019-03-05 Final version of 4 MHz clock PCB
    [CrystalOscillator.kicad_pcb]
2019-03-12 Redesign the sound card to use a bare Atmega 328P instead of arduino nano
    [soundcard.sch]
2019-03-13 Add power flags to sound card schematic
    [soundcard.sch]
2019-03-29 - Modify Python program to prepare it for Z80 interfacing - Add a short demo in Z80 Assembly for DisplayPI
    [displaypi-pygame.py]
2019-03-31 Add displaypi schematic (Z80-RasPI Bus Interface)
    [displaypi.kicad_pcb, displaypi.sch]
2019-04-03 Redesign IO Decoder to include backplane
    [IODecoder.sch]
2019-04-04 Change connector layouts of IO Decoder to match existing Display port layout on main board
    [IODecoder.sch]
2019-04-08 Add initial (incomplete) version of quiz game in Z80 Assembly
2019-04-10 Various changes to Z80 assembly demo
2019-04-10 Small fixes in displaypi-pygame
    [displaypi-pygame.py]
2019-04-14 Add schematic and code for a simple programmable clock based on ATMega 328P
    [SimpleClock.kicad_pcb, SimpleClock.sch]
2019-04-15 Add a second version of the logic level converter for RasPI, using MOSFETs
    [DisplayPI-MOSFET.kicad_pcb, DisplayPI-MOSFET.sch]
2019-10-15 Add first revision of keyboard code (arduino mega)
    [SimpleClock.kicad_pcb, SimpleClock.sch]
